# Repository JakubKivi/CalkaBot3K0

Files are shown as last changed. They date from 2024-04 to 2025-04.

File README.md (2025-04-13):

# CalkaBot3K0

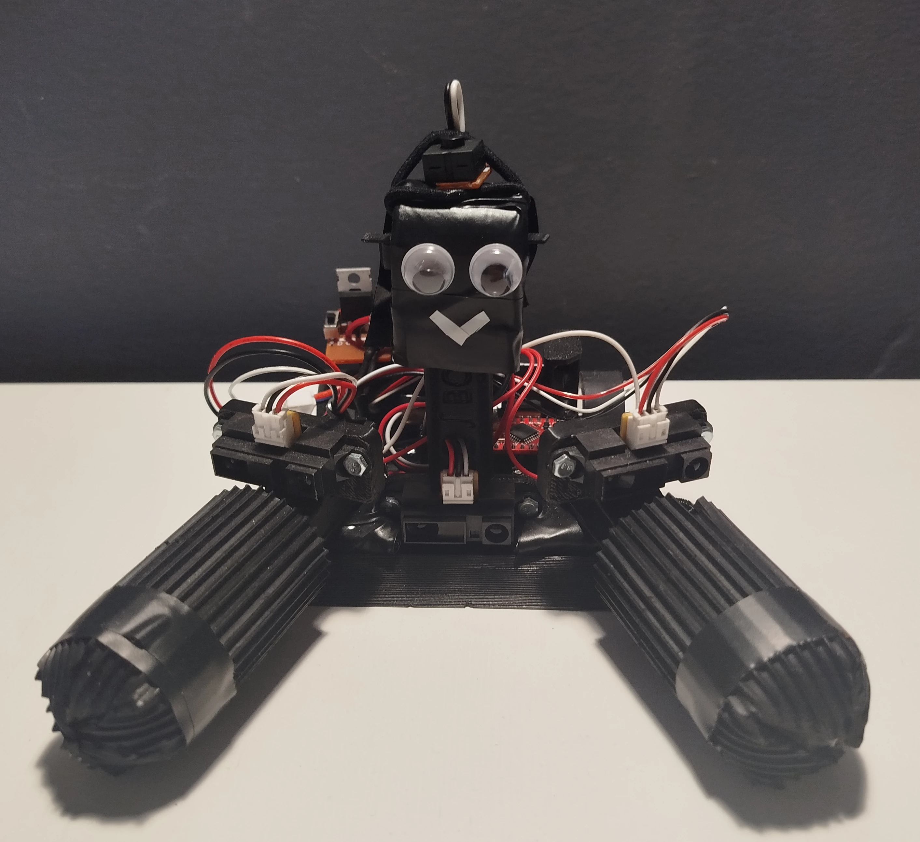
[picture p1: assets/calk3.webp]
CałkaBot3k0


Całkabot 3k0 is a mini-sumo robot equipped with arms designed to lift the opponent. Taking advantage of the lack of size restrictions after the round begins, this beauty you see in the picture unfolds its lifting arms. In the photo, it's already in the fully deployed position.

More info [here](https://jakubkivi.github.io#portfolio-modal-calk3)

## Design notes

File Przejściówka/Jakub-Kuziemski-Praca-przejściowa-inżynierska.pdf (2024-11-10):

# Praca przejściowa inżynierska

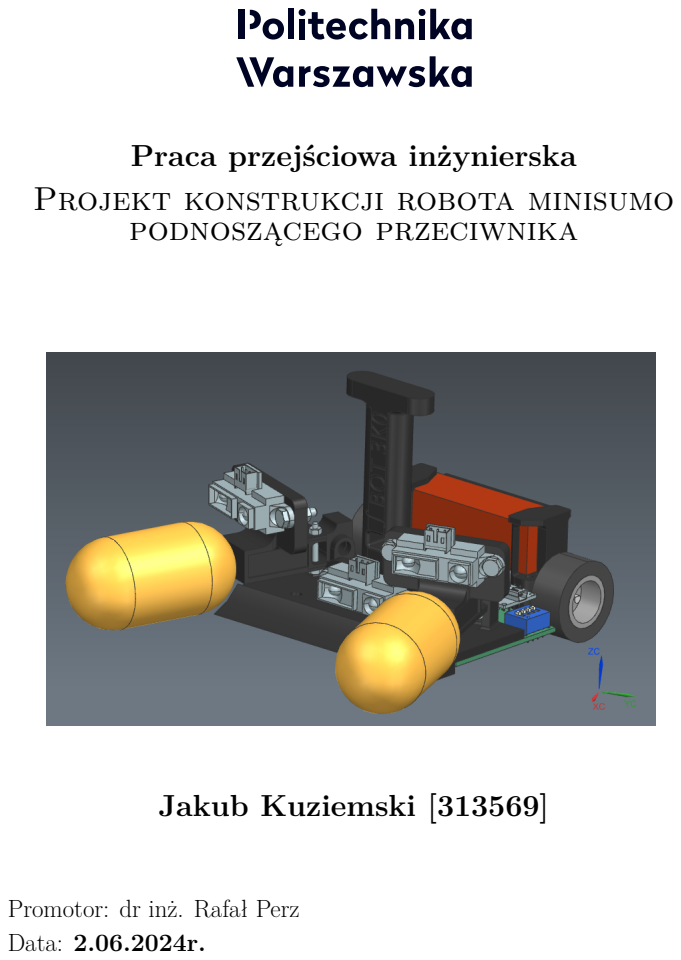
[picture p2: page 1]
podnoszącego przeciwnika; Jakub Kuziemski [313569]

Projekt konstrukcji robota minisumo

Promotor: dr inż. Rafał Perz
Data: 2.06.2024r.

Praca przejściowa inżynierska | Jakub Kuziemski [313569]

## Spis treści

1 Cel pracy | 3
2 Minisumo - wymagania | 3
3 Koncepcja robota minisumo wyposażonego w ramiona | 4
4 Pług robota | 5
5 Ramiona robota | 6
6 Mocowanie baterii | 7
7 Efekty | 8
8 Bibliografia | 10

Projekt konstrukcji robota minisumo podnoszącego przeciwnika Jakub Kuziemski [313569]

## 1 Cel pracy

Celem poniższej pracy jest zaprojektowanie konstrukcji robota klasy minisumo wyposażonego w rozkładane ramiona do podnoszenia przeciwników. Konstrukcja powinna spełniać wszystkie standardowe wymogi jakie musi spełniać robot minisumo, w tym określone wymiary i wagę. Ponadto, projekt powinien uwzględniać integrację wszystkich niezbędnych komponentów, takich jak czujniki, silniki, akumulatory oraz system sterowania, aby zapewnić pełną funkcjonalność robota w warunkach konkurencji minisumo. Niniejsza konstrukcja ma być możliwa do wydrukowania na drukarce 3D.

## 2 Minisumo - wymagania

Zawody walk robotów, na różnych płaszczyznach, są popularną formą zarówno edukacji w dziedzinie robotyki, jak i rozrywki samych konstruktorów. Zawody sumo jako jedne z nich, zyskały sobie znaczną popularność. Konkurencja ta polega na, autonomicznej rywalizacji robotów, nawiązując do tradycyjnych japońskich zapasów sumo. Celem rywalizacji jest wypchnięcie przeciwnika poza okrągłą arenę zwaną dohyo, przy zachowaniu pełnej autonomii działania. Walki sumo podzielone zostały na różne kategorie, w których ograniczają je wymiary i waga. Roboty klasy minisumo nie mogą przekroczyć, w momencie startu, rozmiarów 100x100mm, ani wagi 500g. Nie mają za to określonej maksymalnej wysokości, co zostanie wykorzystane w niniejszym projekcie. Konstrukcje są wyposażone w różnorodne czujniki, takie jak czujniki odległości, linii czy niekiedy nawet akcelerometry. Przy pomocy danych z owych czujników, za pomocą napisanego wcześniej programu robot musi namierzyć przeciwnika, a następnie, nie opuszczając samemu ringu, wypchnąć go. Wartymi nadmienienia ograniczeniami są także zakazy: intencjonalnego zakłócania odczytów przeciwnika, uszkadzania dohyo, strzelania, rzucania, intencjonalnego uszkadzania przeciwnika, a także przytwierdzania się do ziemi.

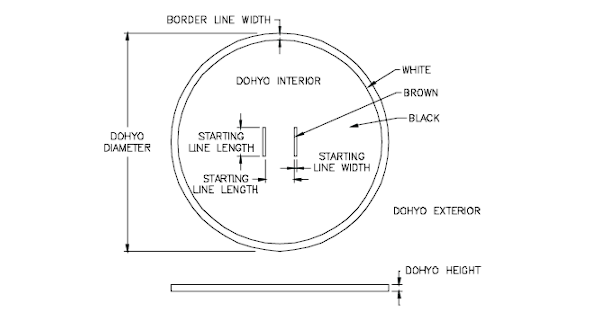
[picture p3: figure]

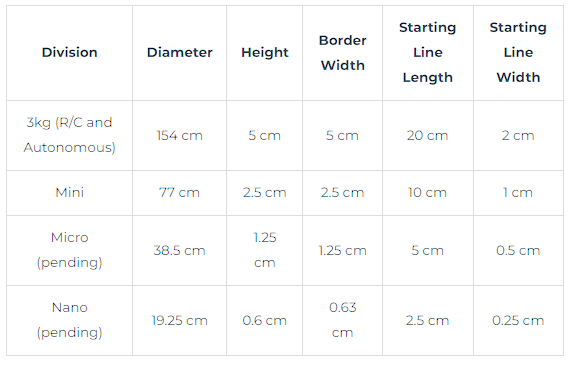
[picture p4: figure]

Ilustracja 1: Specyfikacja ringu w zależności od kategorii na zawodach "Robothon" w USA

## 3 Koncepcja robota minisumo wyposażonego w ramiona

Sformułowane wyżej wymagania, skumulowane z dość długą historią zawodów, stworzyły warunki do powstania preferowanych strategii i rozwiązań konstrukcyjnych. Roboty najczęściej mają masę dokładnie 500g, nisko osadzony środek ciężkości, kilka czujników zbliżeniowych do detekcji przeciwnika, dwa silniki z tyłu oraz niekiedy transoptory do wykrycia linii (nie jest to nawet konieczne przy niektórych strategiach).

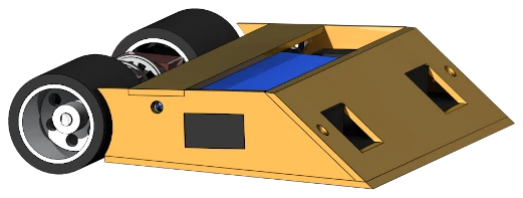
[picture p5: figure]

Ilustracja 2: Przykład najczęściej pojawiającego się robota minisumo

Brak ograniczenia co do wysokości robota daje jednak możliwości rozpatrywania nowych strategii. Niekiedy na zawodach pojawiają się roboty z rozkładanymi ramionami z białym materiałem, który ma zmylić przeciwnika.

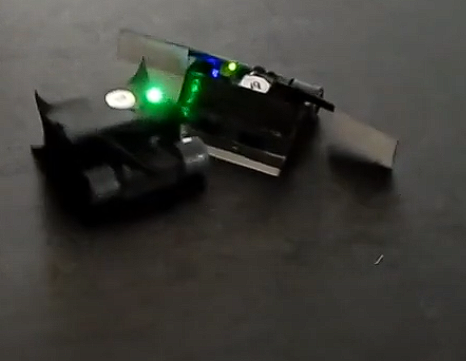
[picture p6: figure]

Ilustracja 3: Robot z rozkładanym mechanizmem dezorientacyjnym w zwarciu, na zawodach Robochallange w Meksyku

W związku z powyższym można postulować, zbudowanie robota z rozkładanymi ramionami, które będą nie tylko dezorientować przeciwnika, ale także, będą mogły go unieść. W korzystnym scenariuszu, w którym roboty spotkają się w zwarciu frontalnym, powodowałoby to zmniejszenie przyczepności oponenta, a w rezultacie wypchnięcie go poza Dohyo.

## 4 Pług robota

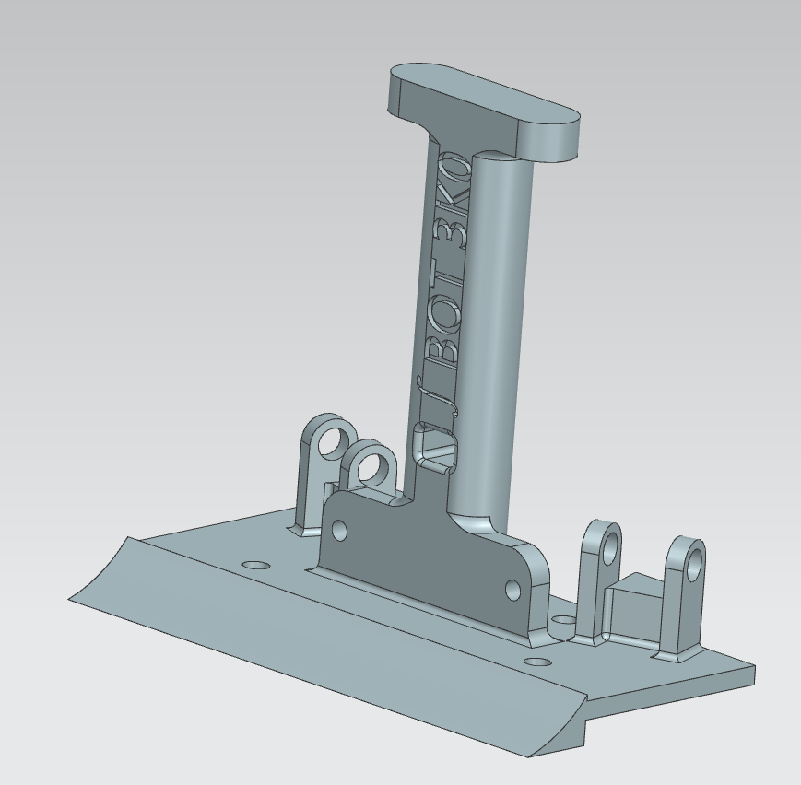
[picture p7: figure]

Ilustracja 4: Pług robota

Pracę rozpoczęto od budowy pługa. Jest to niewątpliwie jeden z kluczowych elementów każdego robota minisumo. Podniesienie przeciwnika jest często czynnikiem warunkującym zwycięstwo, dlatego konstruktorzy starają się aby pług był możliwie najniżej. Przy konstrukcji dwukołowej jest on najczęściej po prostu oparty o ziemie. Także w tym przypadku zdecydowano się na taką konstrukcje. Frontalna część w opisywanym robocie ma jednak inne ważne zadania, które zostały uwzględnione w jego budowie. Cztery otwory ϕ4mm służą do połączenia robota z płytką sterującą, która jednocześnie będzie częścią konstrukcji. Opcjonalnie w razie potrzeb można wykorzystać otwory do montażu ołowiu w celu dociążenia konstrukcji. W centralnej części pługa dostępne jest mocowanie do zamontowania czujnika Sharp GP2Y0A41SK0F. Jest to jeden z najpopularniejszych czujników zbliżeniowych stosowanych na zawodach minisumo. Cechuje go duża niezawodność i dokładność, niestety kosztem dość dużych rozmiarów. Ponadto tuż nad nim znajduje się słupek, który jest częścią prostego mechanizmu rozkładania się ramion robota. W środku słupka wykonano otwór na przewody w celu lepszej ich organizacji. Symetrycznie po obu stronach pługa będą montowane ramiona robota, przy pomocy sworzni. Jednocześnie konstrukcja ta wraz z konstrukcją ramienia tworzą ogranicznik, tak aby ramie nie mogło rozłożyć się do tyłu.

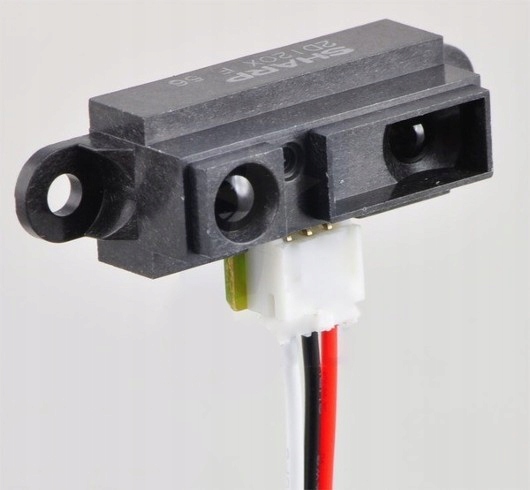
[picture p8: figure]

Ilustracja 5: Czujnik Sharp GP2Y0A41SK0F

## 5 Ramiona robota

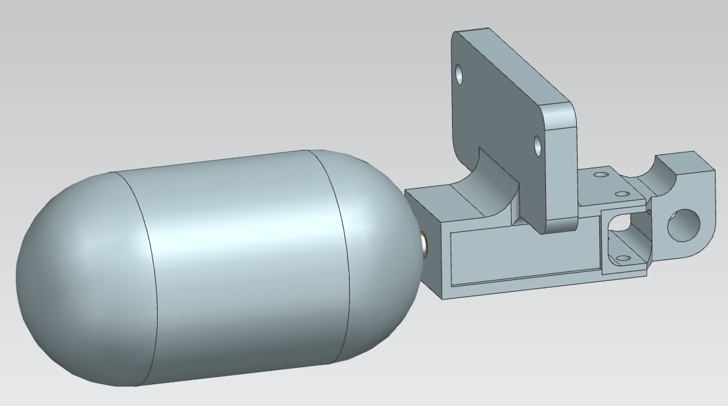
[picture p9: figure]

Ilustracja 6: Projekt ręki robota

Kluczowym elementem opisywanej konstrukcji są oczywiście ramiona. Ramię robota składa się z dwóch skręcanych ze sobą elementów. Pomiędzy nimi ma znajdować się silnik Pololu 998, który jest jednym z najpopularniej stosowanych silników w robotach minisumo, z racji na swoją dużą moc w sosunku do rozmiarów. Ramię jest tak skonstruowane, że silnik pomiędzy dwoma jego częściami jest nie tylko unieruchomiony, ale także odizolowany od kurzu czy włosów, co istotne dla niezawodności działania przekładni. W górnej częsci ramienia skonstruowano mocowanie dla kolejnego czujnika GP2Y0A41SK0F. Poza otworami na śruby łączące obie części ramienia, stworzono też oczywiście otwór na wał silnika. Część mocowana do wału jest zamodelowana poglądowo i jako, że nie będzie drukowana, pozostaje poza obszarem niniejszej pracy. Tylna część konstrukcji ramienia ma też otwór na przewody do silnika, a także otwór do współpracy z pługiem o czym była mowa w rozdziale 4.

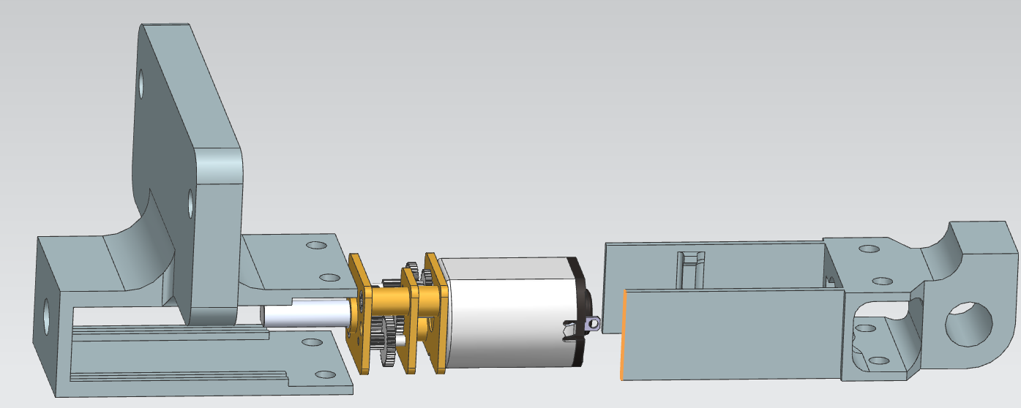
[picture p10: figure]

Ilustracja 7: Rozłożona ręka robota

## 6 Mocowanie baterii

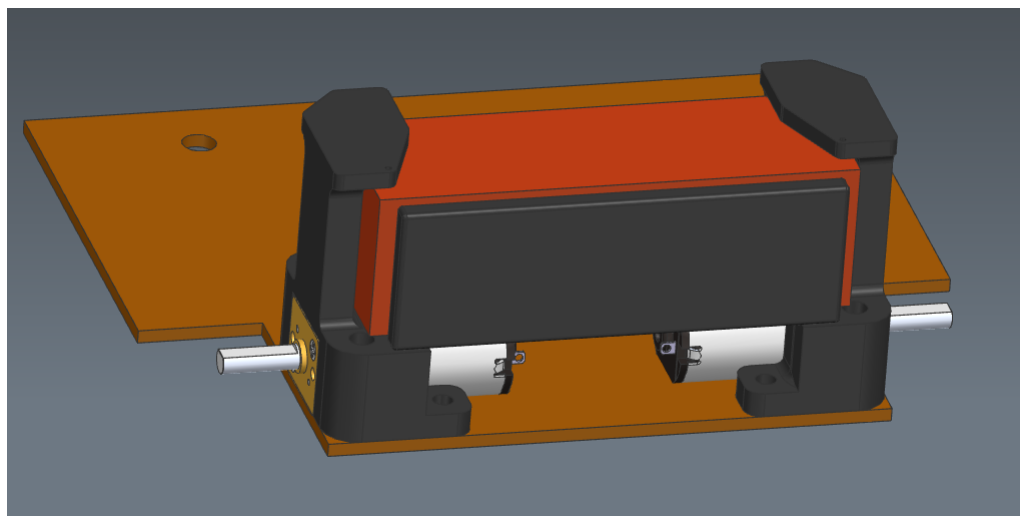
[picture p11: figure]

Ilustracja 8: Mocowanie baterii i silników wraz z modelem baterii (czerwony) i płytki (pomarańczowy)

Tylna część konstrukcji robota jest odpowiedzialna za trzymanie baterii, oraz mocowanie silników do płytki PCB. Można podzielić ją na 3 części. Dwa odbite symetrycznie elementy przytwierdzone do płytki przy pomocy 3 śrub M3 utrzymują silniki w bezruchu, ale także (ponownie) izolują przekładnie od ewentualnych zabrudzeń. Pozostała część tych elementów jest zaprojektowana by odebrać możliwość ruchu baterii we wszystkich kierunkach poza tyłem robota. Tam zaprojektowano trzeci element który można wyjąć na czas zmiany akumulatora, lub włożyć tak aby kompletnie uniemożliwić jego ruch.

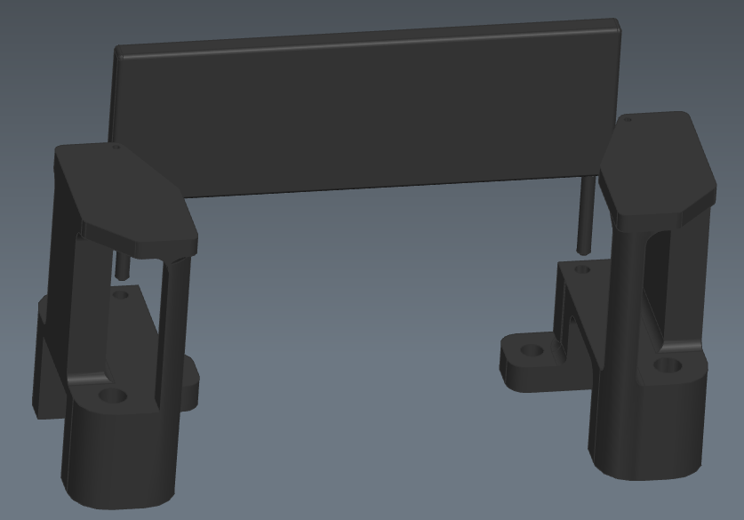
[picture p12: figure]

Ilustracja 9: Rozłożone mocowanie baterii

## 7 Efekty

Łącząc wszystkie wyżej wymienione elementy, oraz dodając kilka gotowych lub poglądowych, otrzymujemy projekt robota minisumo wyposażonego w ramiona, zdolne do podnoszenia przeciwników. Robot rozpoczyna walkę w konfiguracji widocznej na ilustracji 10. Następnie następuje start silników w ramionach i robot odpycha się od słupka zamontowanego na pługu i przechodzi do konfiguracji widocznej na ilustracji 11. Przy pomocy zestawu czujników, robot ma lokalizować przeciwnika, a następnie gdy ten znajdzie się pomiędzy jego ramionami unieść go kręcącymi się nadal silnikami.

Widoczna konstrukcja pokazuje, że w kategorii robotów minisumo, można zaprojektować robota zdolnego do rozkładania własnych ramion, a następnie podniesienia nimi przeciwnika. Niniejsza praca stanowi dobrą podstawę do zbudowania takiego robota i przeprowadzenia testów praktycznych takiego rozwiązania.

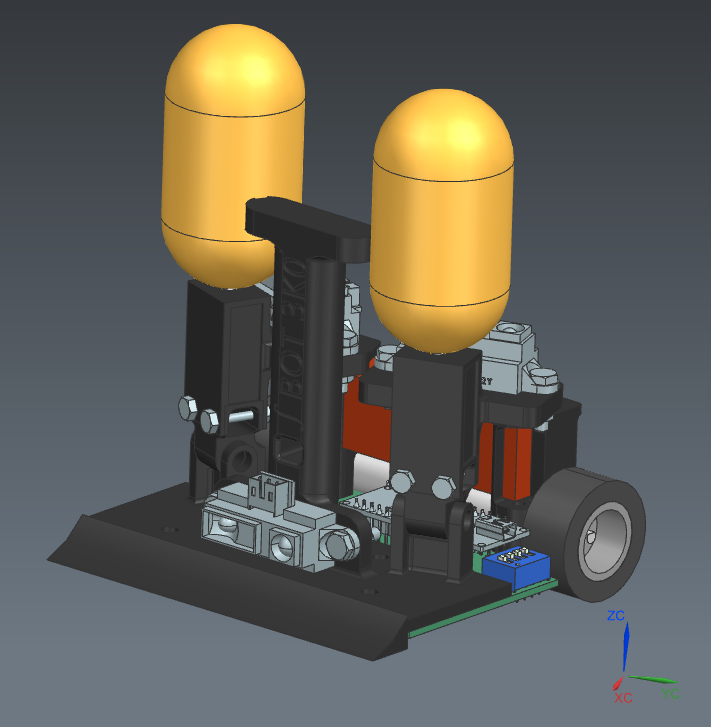
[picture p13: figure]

Ilustracja 10: Kompletna konstrukcja robota

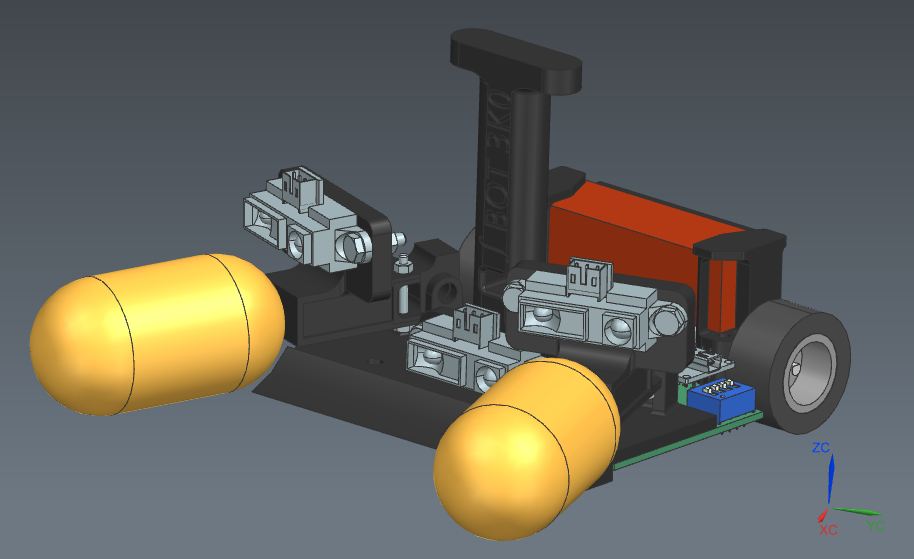
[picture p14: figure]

Ilustracja 11: Kompletna konstrukcja robota z rozłożonymi ramionami

## 8 Bibliografia

1. https://robothon.org/rules-sumo/
2. https://mdrwiega.com/robot-minisumo-banshee/
3. Ja mam Robot!, "Komputer Świat Ekspert" 2007

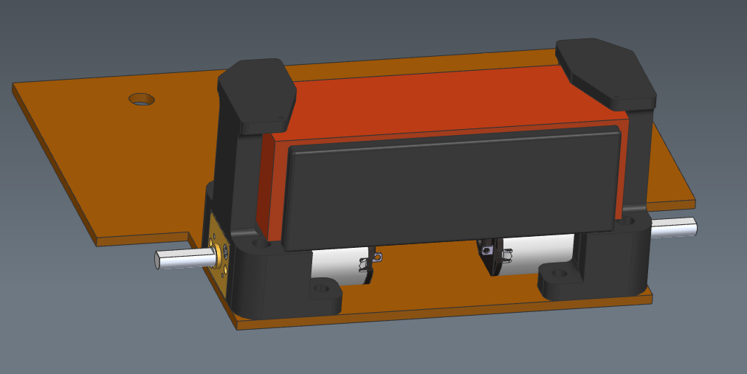
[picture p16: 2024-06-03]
Przejściówka/mocowaniebaterii.PNG

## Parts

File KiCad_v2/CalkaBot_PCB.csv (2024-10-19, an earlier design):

Reference | Value | Datasheet | Footprint | Qty | DNP
A1 | Arduino_Nano_v2.x | https://www.arduino.cc/en/uploads/Main/ArduinoNanoManual23.pdf | Module:Arduino_Nano | 1
C1 | 0u33 | ~ | Capacitor_SMD:C_0805_2012Metric_Pad1.18x1.45mm_HandSolder | 1
C2,C7,C9,C11,C12 | 0u1 | ~ | Capacitor_SMD:C_0805_2012Metric_Pad1.18x1.45mm_HandSolder | 5
C3 | 10n | ~ | Capacitor_SMD:C_0805_2012Metric_Pad1.18x1.45mm_HandSolder | 1
C4 | 200n | ~ | Capacitor_SMD:C_0805_2012Metric_Pad1.18x1.45mm_HandSolder | 1
C5,C6 | 5n6 | ~ | Capacitor_SMD:C_0805_2012Metric_Pad1.18x1.45mm_HandSolder | 2
C8 | 100u | ~ | Capacitor_SMD:CP_Elec_8x10.5 | 1
CR1 | L6225PD | L6225PD | Package_SO:SO-20-1EP_7.52x12.825mm_P1.27mm_EP6.045x12.09mm_Mask3.56x4.47mm_ThermalVias | 1
D1,D2 | 1N4148WT | https://www.diodes.com/assets/Datasheets/ds30396.pdf | Diode_SMD:D_SOD-523 | 2
D3 | SS14 | ~ | Diode_SMD:D_SMA_Handsoldering | 1
J1,J2,J3 | Conn_01x03_Pin | ~ | Connector_JST:JST_PH_B3B-PH-K_1x03_P2.00mm_Vertical | 3
J4 | Conn_01x02_Pin | ~ | Connector_PinHeader_2.54mm:PinHeader_1x02_P2.54mm_Vertical | 1
J5 | MOTOR3 | ~ | Connector_PinHeader_2.54mm:PinHeader_1x02_P2.54mm_Vertical | 1
J6 | StartModule | ~ | Connector_PinHeader_2.54mm:PinHeader_1x03_P2.54mm_Vertical | 1
M1 | Motor_Right | ~ | CalkaBot3k0:CalkBot3k0_Motor_Right | 1
M2 | Motor_Left | ~ | CalkaBot3k0:CalkBot3k0_Motor_Left | 1
Q1,Q2 | KTIR0711S | KTIR0711S | footprints:KTIR0711S_KNB | 2
Q3 | IRLL014NTRPBF | http://www.b-kainka.de/Daten/Transistor/BC108.pdf | Package_TO_SOT_SMD:SOT-223 | 1
R1,R3 | 20k | ~ | Resistor_SMD:R_0805_2012Metric_Pad1.20x1.40mm_HandSolder | 2
R2 | 100R | ~ | Resistor_SMD:R_0805_2012Metric_Pad1.20x1.40mm_HandSolder | 1
R4,R5 | 220 | ~ | Resistor_SMD:R_0805_2012Metric_Pad1.20x1.40mm_HandSolder | 2
R6,R7 | 100k | ~ | Resistor_SMD:R_0805_2012Metric_Pad1.20x1.40mm_HandSolder | 2
SW1 | SW_DIP_x04 | ~ | Button_Switch_THT:SW_DIP_SPSTx04_Slide_9.78x12.34mm_W7.62mm_P2.54mm | 1
U1 | L78M05CDT-TR |  | L78M05CDT-TR:VREG_L78M05CDT-TR | 1

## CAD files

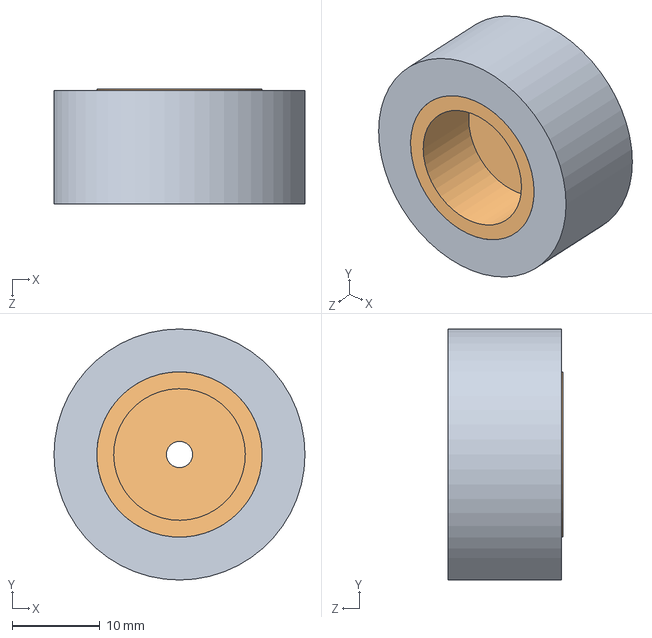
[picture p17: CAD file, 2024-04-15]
NX/wheel-solarbotics-rw2i-internally-mounted-1.snapshot.4/koło_solarbotics.SLDASM
28.6 x 28.6 x 13.1 mm
opona solarbotics
felga_solarbotics

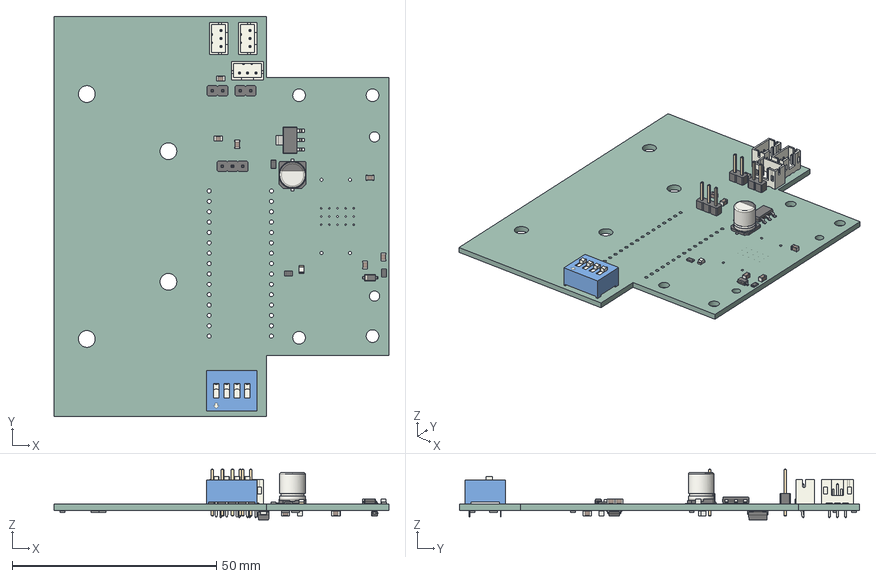
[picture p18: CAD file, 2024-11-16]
NX/CalkaBot_PCB.step
82.0 x 98.0 x 12.5 mm
LED_0805_2012Metric
CP_Elec_63x77
SOT_223
C_0805_2012Metric x 10
SW_DIP_SPSTx04_Slide_978x1234mm_W762mm_P254mm
R_0805_2012Metric x 9
PinHeader_1x02_P254mm_Vertical x 2
PinHeader_1x03_P254mm_Vertical
JST_B3B_PH_K x 3
D_SOD_123 x 2
D_SMA
CalkaBot_PCB_PCB

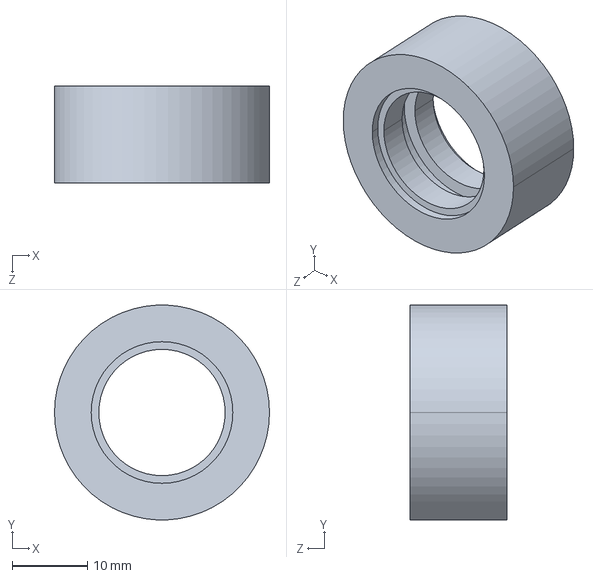
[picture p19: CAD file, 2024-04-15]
NX/wheel-solarbotics-rw2i-internally-mounted-1.snapshot.4/STEP/opona solarbotics.STEP
28.6 x 28.6 x 13.0 mm

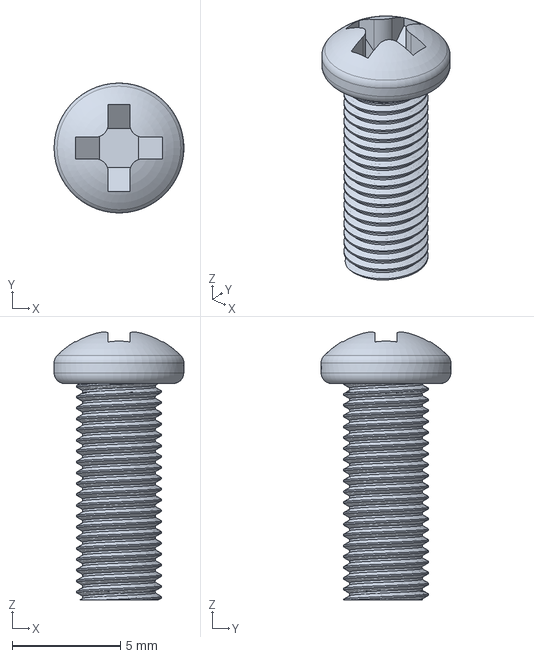
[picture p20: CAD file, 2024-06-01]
NX/M4 x 10mm.step
6.00 x 6.00 x 12.4 mm

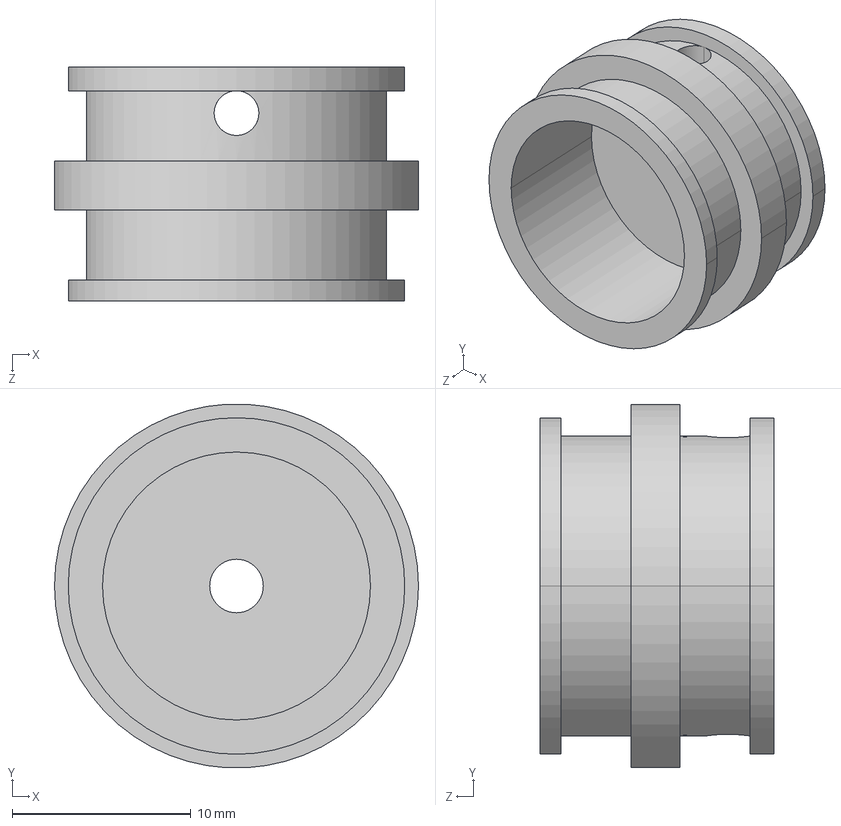
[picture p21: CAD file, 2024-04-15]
NX/wheel-solarbotics-rw2i-internally-mounted-1.snapshot.4/STEP/felga_solarbotics.STEP
20.4 x 20.4 x 13.1 mm

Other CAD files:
NX/Akumulator.prt
NX/ArduinoNano.prt
NX/CP_Elec_8x10.5.prt
NX/CP_Elec_8x105.prt
NX/C_0805_2012Metric.prt
NX/C_0805_2012Metric1576.prt
NX/CalkaBot_PCB.prt
NX/CalkaBot_PCB_step.prt
NX/D_SMA.prt
NX/D_SMA17935.prt
NX/D_SOD-523.prt
NX/D_SOD_523.prt
NX/GP2Y0A21YK0F.prt
NX/JST_B3B_PH_K.prt
NX/JST_B3B_PH_K11783.prt
NX/JST_PH_B3B-PH-K_1x03_P2.00mm_Vertical.prt
NX/JST_PH_B3B-PH-K_1x03_P2.00mm_Vertical11760.prt
NX/M2_Nakretka.prt
NX/M2_Sruba.prt
NX/M3_Nakretka.prt
NX/M3_Sruba.prt
NX/M4 x 10mm_step.prt
NX/Obudowa_Reki.prt
NX/Obudowa_Reki_Tyl.prt
NX/PinHeader_1x02_P2.54mm_Vertical.prt
NX/PinHeader_1x02_P254mm_Vertical.prt
NX/PinHeader_1x03_P2.54mm_Vertical.prt
NX/PinHeader_1x03_P254mm_Vertical.prt
NX/Podstawa.prt
NX/R_0805_2012Metric.prt
NX/R_0805_2012Metric10951.prt
NX/Reka_Zlozenie.prt
NX/SOT-223.prt
NX/SOT_223.prt
NX/SW_DIP_SPSTx04_Slide_9.78x12.34mm_W7.62mm_P2.54mm.prt
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

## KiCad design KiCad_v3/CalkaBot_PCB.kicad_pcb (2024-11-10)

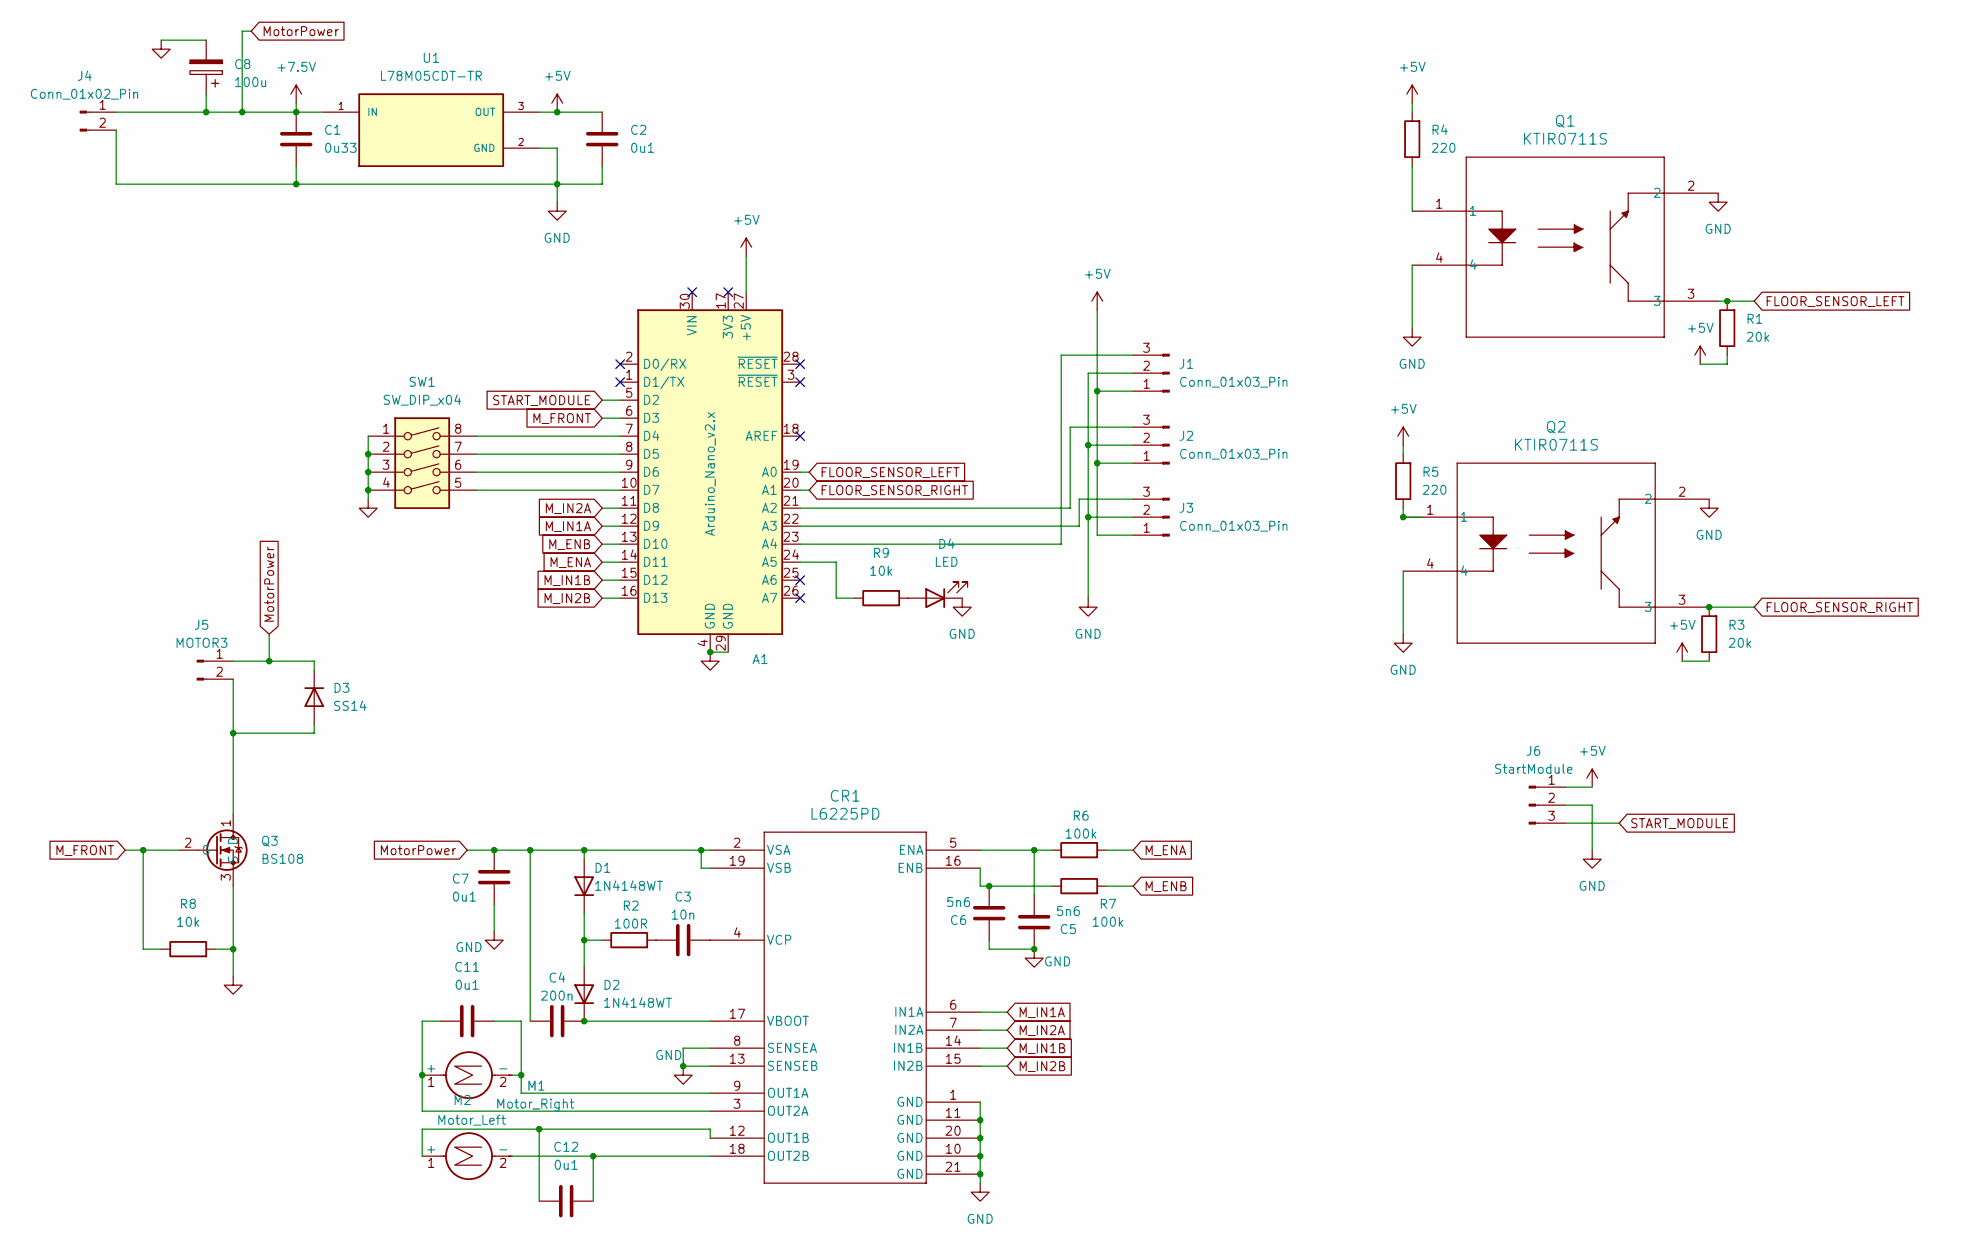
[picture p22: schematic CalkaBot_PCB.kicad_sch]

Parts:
A1: Arduino_Nano_v2.x; Arduino_Nano
C1: 0u33; C_0805_2012Metric_Pad1.18x1.45mm_HandSolder
C2, C7, C11, C12: 0u1; C_0805_2012Metric_Pad1.18x1.45mm_HandSolder
C3: 10n; C_0805_2012Metric_Pad1.18x1.45mm_HandSolder
C4: 200n; C_0805_2012Metric_Pad1.18x1.45mm_HandSolder
C5, C6: 5n6; C_0805_2012Metric_Pad1.18x1.45mm_HandSolder
C8: 100u; CP_Elec_6.3x7.7
CR1: L6225PD
D1, D2: 1N4148WT; D_SOD-123
D3: SS14; D_SMA_Handsoldering
D4: LED; LED_0805_2012Metric_Pad1.15x1.40mm_HandSolder
J1, J2, J3: Conn_01x03_Pin; JST_PH_B3B-PH-K_1x03_P2.00mm_Vertical
J4: Conn_01x02_Pin; PinHeader_1x02_P2.54mm_Vertical
J5: MOTOR3; PinHeader_1x02_P2.54mm_Vertical
J6: StartModule; PinHeader_1x03_P2.54mm_Vertical
M1: Motor_Right; CalkBot3k0_Motor_Right
M2: Motor_Left; CalkBot3k0_Motor_Left
Q1, Q2: KTIR0711S
Q3: BS108; SOT-223-IRLL014NTRPBF
R1, R3: 20k; R_0805_2012Metric_Pad1.20x1.40mm_HandSolder
R2: 100R; R_0805_2012Metric_Pad1.20x1.40mm_HandSolder
R4, R5: 220; R_0805_2012Metric_Pad1.20x1.40mm_HandSolder
R6, R7: 100k; R_0805_2012Metric_Pad1.20x1.40mm_HandSolder
R8, R9: 10k; R_0805_2012Metric_Pad1.20x1.40mm_HandSolder
SW1: SW_DIP_x04; SW_DIP_SPSTx04_Slide_9.78x12.34mm_W7.62mm_P2.54mm
U1: L78M05CDT-TR; VREG_L78M05CDT-TR; PARTREV 24

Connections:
+5V: A1.27 (+5V), C2.1, J1.1, J2.1, J3.1, J6.1, R1.1, R3.1, R4.2, R5.2, U1.3 (OUT)
FLOOR_SENSOR_LEFT: A1.19 (A0), Q1.3, R1.2
FLOOR_SENSOR_RIGHT: A1.20 (A1), Q2.3, R3.2
GND: A1.4 (GND), A1.29 (GND), C1.2, C2.2, C5.1, C6.1, C7.2, C8.2, CR1.1 (GND), CR1.8 (SENSEA), CR1.10 (GND), CR1.11 (GND), CR1.13 (SENSEB), CR1.20 (GND), CR1.21 (GND), D4.1 (K), J1.2, J2.2, J3.2, J4.2, J6.2, Q1.2, Q1.4, Q2.2, Q2.4, Q3.3 (S), R8.2, SW1.1, SW1.2, SW1.3, SW1.4, U1.2 (GND); also elsewhere on the board
M_ENA: A1.14 (D11), R6.2
M_ENB: A1.13 (D10), R7.2
M_FRONT: A1.6 (D3), Q3.2 (G), R8.1
M_IN1A: A1.12 (D9), CR1.6 (IN1A)
M_IN1B: A1.15 (D12), CR1.14 (IN1B)
M_IN2A: A1.11 (D8), CR1.7 (IN2A)
M_IN2B: A1.16 (D13), CR1.15 (IN2B)
MotorPower: C1.1, C4.1, C7.1, C8.1, CR1.2 (VSA), CR1.19 (VSB), D1.2 (A), D3.1 (K), J4.1, J5.1, U1.1 (IN); also elsewhere on the board
unnamed: A1.21 (A2), J2.3
unnamed: A1.22 (A3), J3.3
unnamed: A1.23 (A4), J1.3
unnamed: A1.24 (A5), R9.1
unnamed: A1.7 (D4), SW1.8
unnamed: A1.8 (D5), SW1.7
unnamed: A1.9 (D6), SW1.6
unnamed: A1.10 (D7), SW1.5
unnamed: C3.1, R2.2
unnamed: C5.2, CR1.5 (ENA), R6.1
unnamed: C6.2, CR1.16 (ENB), R7.1
unnamed: C11.1, CR1.9 (OUT1A), M1.2 (-)
unnamed: C12.2, CR1.12 (OUT1B), M2.1 (+)
unnamed: C11.2, CR1.3 (OUT2A), M1.1 (+)
unnamed: C12.1, CR1.18 (OUT2B), M2.2 (-)
unnamed: C4.2, CR1.17 (VBOOT), D2.1 (K)
unnamed: C3.2, CR1.4 (VCP)
unnamed: D1.1 (K), D2.2 (A), R2.1
unnamed: D3.2 (A), J5.2, Q3.1 (D)
unnamed: D4.2 (A), R9.2
unnamed: Q1.1, R4.1
unnamed: Q2.1, R5.1
START_MODULE: A1.5 (D2), J6.3

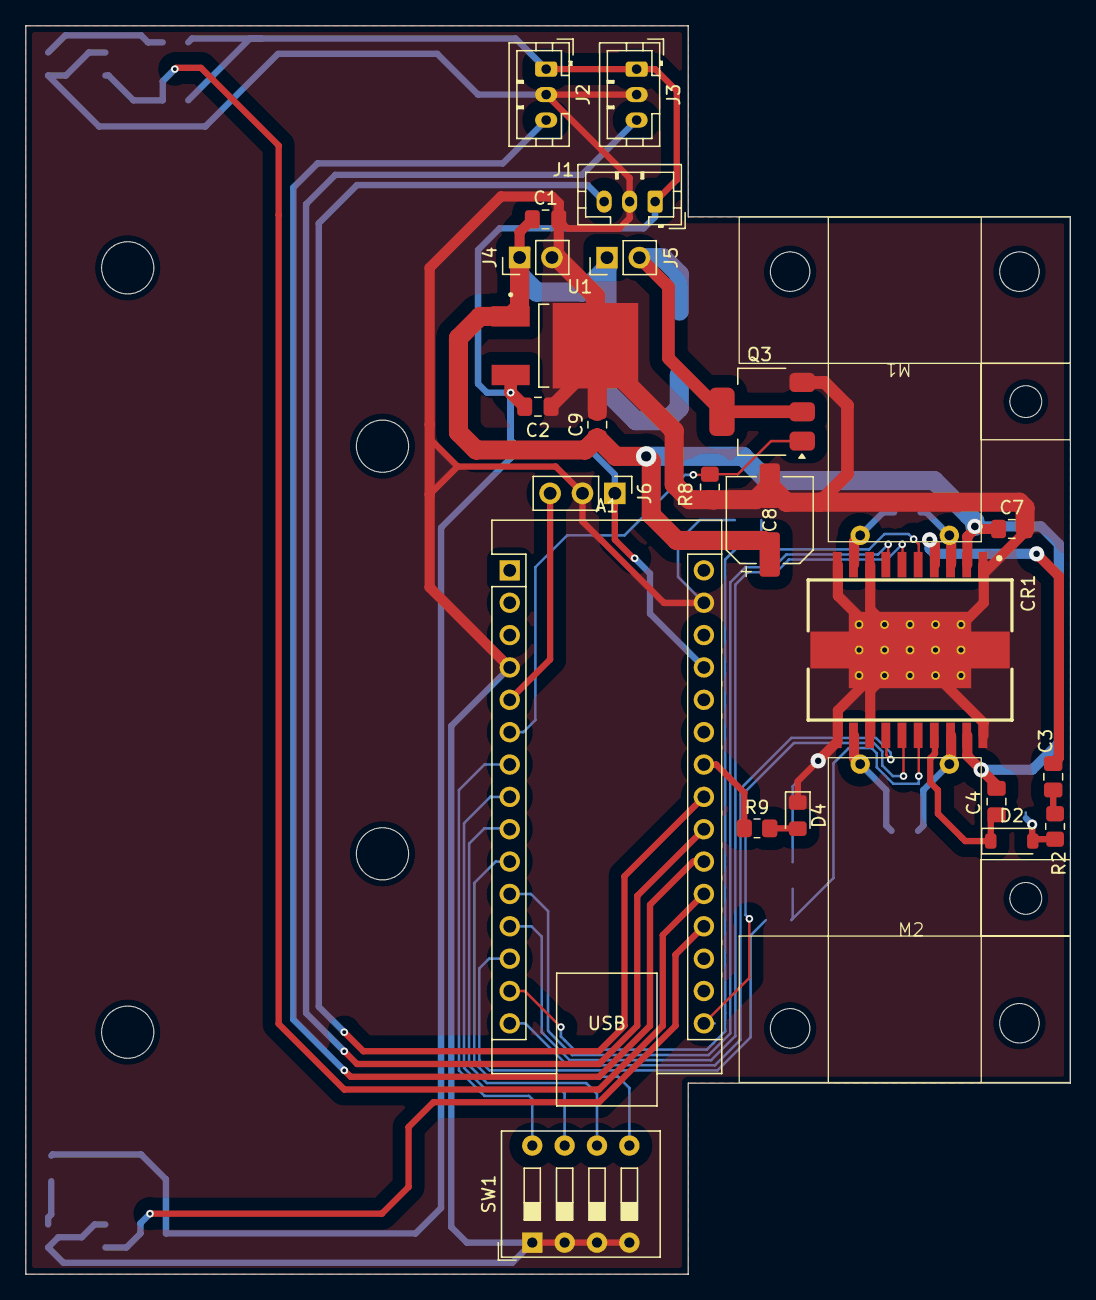
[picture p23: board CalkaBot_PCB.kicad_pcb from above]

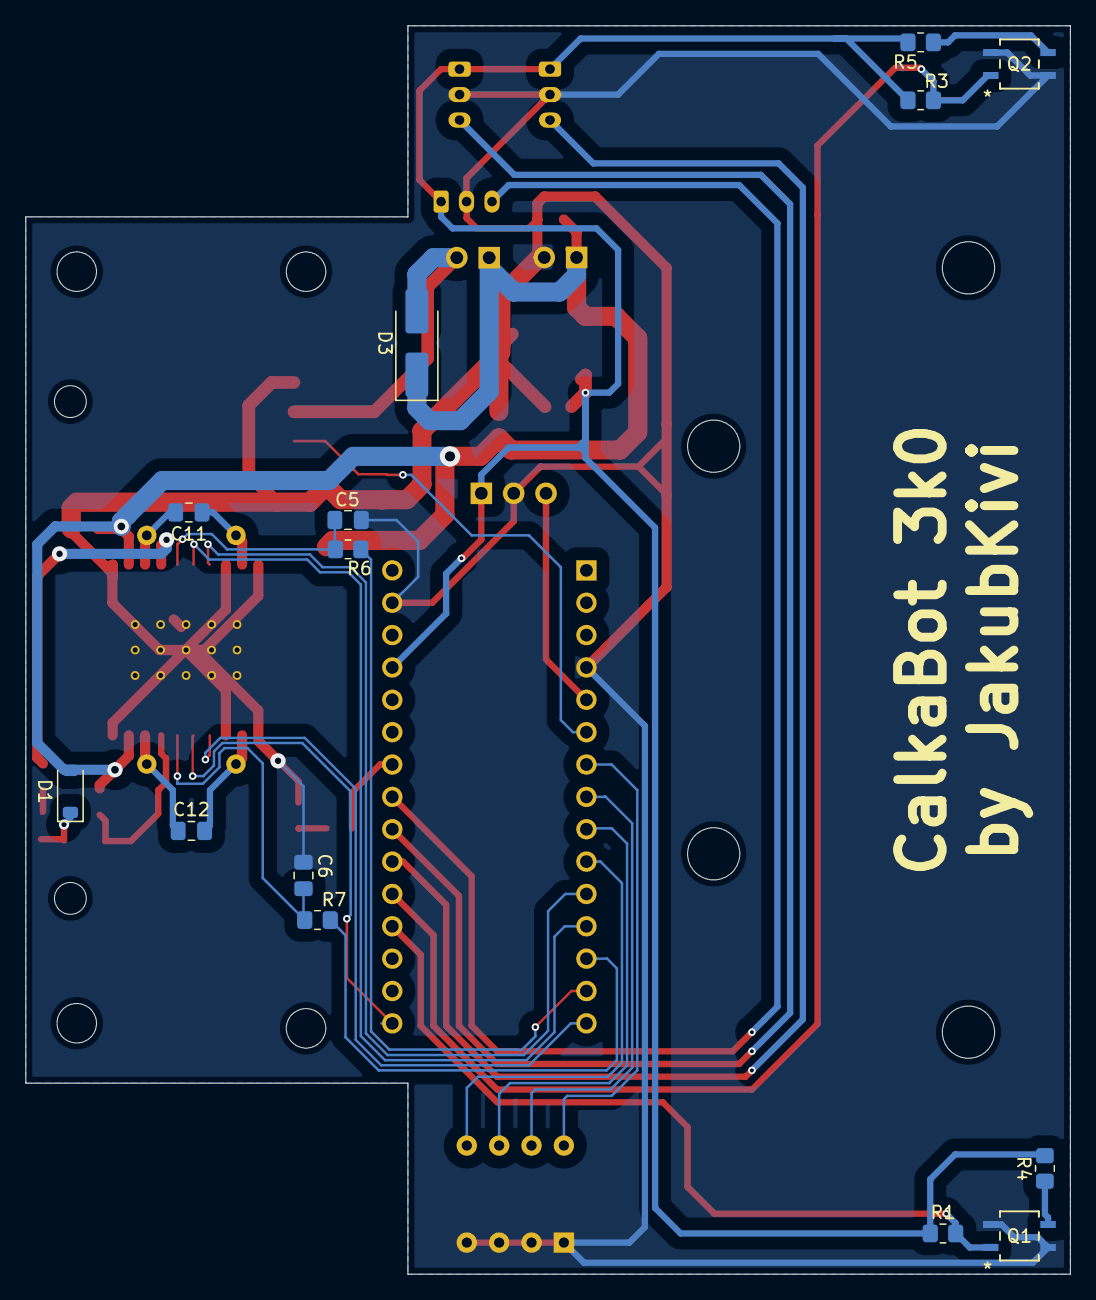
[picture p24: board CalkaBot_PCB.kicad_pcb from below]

Board: 2 copper layers, 82.0 x 98.0 mm, 39 parts (14 on the bottom side), 35 nets.

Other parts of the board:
C9: 0u1; C_0805_2012Metric_Pad1.18x1.45mm_HandSolder

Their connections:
GND: C9.2; also elsewhere on the board
MotorPower: C9.1; also elsewhere on the board

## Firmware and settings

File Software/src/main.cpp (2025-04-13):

#include "../include/config.h"
#include "../include/FrontMotor.h"  
#include "../include/InputManager.h"
#include "../include/BuildLED.h"
#include "../include/Sensor.h"
#include "../include/Robot.h"
#include "../lib/SoftPWM.h"



SOFTPWM_DEFINE_CHANNEL(0, ROBOT_RIGHT_DDR, ROBOT_RIGHT_PORT, ROBOT_RIGHT_PIN);   // Soft PWM na Pin 13
SOFTPWM_DEFINE_CHANNEL(1, ROBOT_LEFT_DDR, ROBOT_LEFT_PORT, ROBOT_LEFT_PIN);      // Soft PWM na Pin 12
SOFTPWM_DEFINE_OBJECT_WITH_PWM_LEVELS(2, 255);                                   // Makra dla SoftPWM

Robot calkaBot(&DDRB, &PORTB, PB3, PB0, PB2, PB1);                      // Silniki w kołach
InputManager inputManager(&PORTD, &DDRD, &PIND, PD4, PD5, PD6, PD7);    // Switche na płytce
FrontMotor frontMotor(&PORTD, &DDRD, PD3);                              // Sterowanie ramionami
BuildLed buildLed(&PORTC, &DDRC, PC5);                                  // Wbudowana dioda informacyjna

Sensor floorLeft(0);                                                    // Czujniki linii, lewy
Sensor floorRight(1);                                                   //               , prawy

Sensor front(3);                                                        // Czujniki przeciwnika , środkowy
Sensor left(4);                                                         //                      , lewy
Sensor right(2);                                                        //                      , prawy


void setup() {
    Palatis::SoftPWM.begin(200);  
    Palatis::SoftPWM.set(0, FULL_SPEED); 
    Palatis::SoftPWM.set(1, FULL_SPEED);    //dla pozycjonowania na starcie

    pinMode(2, INPUT_PULLUP);
    Serial.begin(9600);

}

bool positioned = false;

bool curve = true;

void loop() {
    if (digitalRead(2) or inputManager.readDecimalValue() ==0){  
        switch (inputManager.readDecimalValue())
        {
            case 0:
                positioned = false;
                calkaBot.stop();
                frontMotor.off();
                Serial.println("Left: "+ String(left.read()) + "    Mid: " + String(front.read()) +"       Right: " + String(right.read() ));
                
                if (front.read() > FRONT_THRESHOLD or right.read() > FRONT_RIGHT_THRESHOLD or left.read() > FRONT_LEFT_THRESHOLD)
                {
                    buildLed.on();
                }else{
                    buildLed.off();
                }
                _delay_ms(500);
            break;
            


            case 1:
            case 2:                    
            case 3:         //lewo bez szukania
            case 5:
            case 6:
            case 7:         //prawo bez szukania
            case 9:
            case 10:
            case 11:        //lewo z szukaniem
            case 13:
            case 14:
            case 15:        //prawo z szukaniem
                if (!positioned)
                {
                    delay(3000);
                    int positioningTime = 1;
                    if(inputManager.readPin(PD4)) positioningTime+=1;
                    if(inputManager.readPin(PD5)) positioningTime+=2;
                    calkaBot.position(&left, &front, &right, positioningTime, inputManager.readPin(PD6));
                    positioned = true; 
                    frontMotor.on();

                }else{

                    if(front.read() > FRONT_FULLSPEED_THRESHOLD){           //NA BLISKO RURA!
                        Palatis::SoftPWM.set(0, FULL_SPEED); 
                        Palatis::SoftPWM.set(1, FULL_SPEED); 
                    }else{
                        Palatis::SoftPWM.set(0, SEARCH_SPEED); 
                        Palatis::SoftPWM.set(1, SEARCH_SPEED); 
                    }

                    if (front.read()>FRONT_THRESHOLD){
                        calkaBot.forward();

                    }else if(right.read() > FRONT_RIGHT_THRESHOLD){
                        calkaBot.rightCurve();

                    }else if(left.read() > FRONT_LEFT_THRESHOLD){
                        calkaBot.leftCurve();

                    }else{
                        if (inputManager.readPin(PD7))        //Kręcenie włączone
                        {
                            if (floorLeft.read() < LEFT_FLOOR_THRESHOLD)
                            {
                                calkaBot.backward();
                                _delay_ms(LINE_DETCTION_BACKWARD_LENGHT);
                                calkaBot.rightTurn();
                                _delay_ms(LINE_DETCTION_RIGHT_TURN_LENGHT);

                            }else if(floorRight.read() < RIGHT_FLOOR_THRESHOLD){
                                calkaBot.backward();
                                _delay_ms(LINE_DETCTION_BACKWARD_LENGHT);
                                calkaBot.rightTurn();
                                _delay_ms(LINE_DETCTION_LEFT_TURN_LENGHT);

                            }else{
                                int i=0;
                                if (curve){
                                    calkaBot.leftTurn();
                                    while (i < SEARCH_LEFT_CURVE){
                                        delay(10);
                                        i+=10;
                                        if (right.read() > FRONT_RIGHT_THRESHOLD || front.read()>FRONT_THRESHOLD || left.read() > FRONT_LEFT_THRESHOLD)
                                            break;
                                        
                                    } 

                                }else{
                                    calkaBot.rightTurn();
                                    while (i < SEARCH_RIGHT_CURVE){
                                        delay(10);
                                        i+=10;
                                        if (right.read() > FRONT_RIGHT_THRESHOLD || front.read()>FRONT_THRESHOLD || left.read() > FRONT_LEFT_THRESHOLD)
                                            break;
                                        
                                    } 
                                }
                                curve = !curve;
                            }
                        }else{
                            calkaBot.stop();
                        }
                    }
                    frontMotor.on();
                    delay(10);
                }
            break;

            case 4:
            case 8:
            case 12:            
                frontMotor.off();
                calkaBot.forward();
                buildLed.toggle();
                _delay_ms(100);
            break;
            
            default:
                positioned = false;
                frontMotor.off();
                calkaBot.stop();
                buildLed.toggle();
                _delay_ms(100);
            break;
        }
    }else{
        positioned = false;
        frontMotor.off();
        calkaBot.stop();
        buildLed.toggle();
        _delay_ms(100);
    }
}

    // ===================================== INŻYNIERKA ====================(tak. z błędami. późno było xd ale padaka xd)======== //
    // while (!positioned)
    // {
    //     if (digitalRead(2))   // Sygnał startowy na złączu J6
    //     {
    //         frontMotor.on();    //Uruchom silniki w ramionach
    //         if (inputManager.readPin(4)) 
    //         {
    //             //Wykonaj program specjalny

    //         }else{
    //             if (inputManager.readPin(1))        //Przodem do siebie
    //             {
    //                 if (inputManager.readPin(2))            //korekta w lewo
    //                 {
    //                     calkaBot.leftTurn();
    //                     delay(ALIGNMENT_TURN_LENGHT);
    //                     positioned=true;
    //                 }else{                                 //korekta w prawo
    //                     calkaBot.rightTurn();
    //                     delay(ALIGNMENT_TURN_LENGHT);
    //                 }
                    
    //             }else{                              //Tyłem do siebie
    //                 if (inputManager.readPin(2))            //korekta w lewo
    //                 {
    //                     calkaBot.leftTurn();
    //                     delay(BACKWARDS_ALIGNMENT_TURN_LENGHT);
    //                 }else{                                 //korekta w prawo
    //                     calkaBot.rightTurn();
    //                     delay(BACKWARDS_ALIGNMENT_TURN_LENGHT);
    //                 }
    //             }
                
    //         }
    //         positioned=true;
    //     }
    // }

    // while(positioned){
    //     if (front.read()>FRONT_THRESHOLD)
    //     {
    //         calkaBot.forward();
    //     }else if(right.read()>FRONT_THRESHOLD){
    //         calkaBot.rightCurve();
    //     }else if(left.read()>FRONT_THRESHOLD){
    //         calkaBot.leftCurve();
    //     }else{
    //         if (inputManager.readPin(3))        //Przeszukiwanie włączone
    //         {
    //             if (floorLeft.read() > LEFT_FLOOR_THRESHOLD || floorRight.read() > RIGHT_FLOOR_THRESHOLD)
    //             {
    //                 calkaBot.backward();
    //                 _delay_ms(LINE_DETCTION_BACKWARD_LENGHT);
    //                 calkaBot.rightTurn();
    //                 _delay_ms(LINE_DETCTION_TURN_LENGHT);
    //             }else{
    //                 calkaBot.forward();
    //             }                
    //         }
    //     }
        
    // }

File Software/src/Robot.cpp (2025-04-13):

#include "../include/Robot.h"
#include "FrontMotor.h"
#include <Arduino.h>
#include "../lib/SoftPWM.h"
#include "../include/config.h"
#include "../include/Sensor.h"


Robot::Robot(volatile uint8_t* ddr, volatile uint8_t* port, 
             uint8_t pinForwardL, uint8_t pinForwardR, uint8_t pinBackwardL, uint8_t pinBackwardR) 
    : ddr(ddr), port(port), pinForwardL(pinForwardL), pinForwardR(pinForwardR), 
      pinBackwardL(pinBackwardL), pinBackwardR(pinBackwardR){

       

        *ddr |= (1 << pinForwardL) | (1 << pinForwardR)
          | (1 << pinBackwardL) | (1 << pinBackwardR);

        *port &= ~((1 << pinForwardL) | (1 << pinForwardR) 
            | (1 << pinBackwardL) | (1 << pinBackwardR));
      }

void Robot::setSpeed(uint8_t speedLeft, uint8_t speedRight) {
    
//   Palatis::SoftPWM.set(0, 255); // Kanał 0 (pin 13): wartość 100
//   Palatis::SoftPWM.set(1, 255); // Kanał 1 (pin 12): wartość 100
    
}

void Robot::forward() {
    *port |= (1 << pinForwardL) | (1 << pinForwardR);
    *port &= ~((1 << pinBackwardL) | (1 << pinBackwardR));
}

void Robot::backward() {
    *port |= (1 << pinBackwardL) | (1 << pinBackwardR);
    *port &= ~((1 << pinForwardL) | (1 << pinForwardR));
}

void Robot::rightTurn() {
    *port |= (1 << pinForwardL) | (1 << pinBackwardR);
    *port &= ~((1 << pinBackwardL) | (1 << pinForwardR));
}

void Robot::leftTurn() {
    *port |= (1 << pinForwardR) | (1 << pinBackwardL);
    *port &= ~((1 << pinForwardL) | (1 << pinBackwardR));
}

void Robot::stop() {
    *port &= ~((1 << pinForwardL) | (1 << pinForwardR) 
             | (1 << pinBackwardL) | (1 << pinBackwardR));
}

void Robot::leftCurve() {
    // Lewe  do przodu, prawe zatrzymane
    

    *port |= (1 << pinForwardR); 
    *port &= ~((1 << pinBackwardR) | (1 << pinForwardL) | (1 << pinBackwardL)); 
}

void Robot::rightCurve() {
    // Prawe do przodu, lewe zatrzymane
    
    *port |= (1 << pinForwardL); 
    *port &= ~((1 << pinBackwardL) | (1 << pinForwardR) | (1 << pinBackwardR)); 
}

void Robot::position(Sensor* left, Sensor* front, Sensor* right, int time, bool direction){
    
    int timeInMs;
    if (direction)
    {
        rightTurn();
        switch (time)
        {
            case 1:
                timeInMs =POSITIONING_RIGHT_TURN_1;
            break;
            case 2:
                timeInMs =POSITIONING_RIGHT_TURN_2;
            break;
            default:
                timeInMs =POSITIONING_RIGHT_TURN_3;
            break;
        }
    }else{
        leftTurn();
        switch (time)
        {
            case 1:
                 timeInMs =POSITIONING_LEFT_TURN_1;
            break;
            case 2:
                timeInMs =POSITIONING_LEFT_TURN_2;
            break;
            default:
                timeInMs =POSITIONING_LEFT_TURN_3;
            break;
        }
    }
    int i = 0;
    while ( i < timeInMs ){
        delay(10);
        i+=10;
        // if(right->read() > FRONT_RIGHT_THRESHOLD || front->read()>FRONT_THRESHOLD || left->read() > FRONT_LEFT_THRESHOLD) //jak coś widzisz to przestań
        //     break;
    }
    
    stop();
}

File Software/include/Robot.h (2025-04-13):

#ifndef ROBOT_H
#define ROBOT_H

#include <avr/io.h>
#include "FrontMotor.h"
#include "../include/Sensor.h"

#define ROBOT_RIGHT_DDR DDRB
#define ROBOT_RIGHT_PORT PORTB
#define ROBOT_RIGHT_PIN PORTB5  

#define ROBOT_LEFT_DDR DDRB
#define ROBOT_LEFT_PORT PORTB
#define ROBOT_LEFT_PIN PORTB4   //Definicje w preprocesorze potrzebne dla poprawnego działania biblioteki SoftPWM

class Robot {
private:
    volatile uint8_t* ddr;    // Wskaźnik na DDR
    volatile uint8_t* port;   // Wskaźnik na PORT
    uint8_t pinForwardL;      // Pin dla lewego przodu
    uint8_t pinForwardR;      // Pin dla prawego przodu
    uint8_t pinBackwardL;     // Pin dla lewego tyłu
    uint8_t pinBackwardR;     // Pin dla prawego tyłu

public:
    Robot(volatile uint8_t* ddr, volatile uint8_t* port, 
          uint8_t pinForwardL, uint8_t pinForwardR, uint8_t pinBackwardL, uint8_t pinBackwardR);

    void setSpeed(uint8_t speed1, uint8_t speed2);

    void forward();
    void backward();
    void leftTurn();
    void rightTurn();
    void leftCurve();
    void rightCurve();
    void stop();

    void position(Sensor* left, Sensor* front, Sensor* right,  int time, bool direction); // 0 - left, 1 - right
};

#endif

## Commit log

2024-04-02 obudowa silnika done
    [Obudowa_Reki.prt, Obudowa_Reki_Tyl.prt, Podstawa.prt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]
2024-04-03 Trzymajka na sharpa
    [Obudowa_Reki.prt, Obudowa_Reki_Tyl.prt, Zlozenie.prt]
2024-04-05 ręka usprawniona, spychacz rozppoczęty
    [CNY-70.prt, GP2Y0A21YK0F.prt, Obudowa_Reki.prt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]
2024-04-15 front sharp connected, setting angle
    [Kepala Servo_SG90.prt, Obudowa_Reki_Tyl.prt, Podstawa.prt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]
2024-04-29 bateria i dupa
    [Akumulator.prt, ArduinoNano.prt, CNY-70.prt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]
2024-05-06 zostaly śrubki chyba
    [Zderzak.prt, Zlozenie_v2.prt, obudowa_tyl.prt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]
2024-05-07 zostaly srubki i klapka z tylu?
    [Obudowa_Reki.prt, Zderzak.prt, Zlozenie_v2.prt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]
2024-05-20 z starego pc
    [Akumulator.prt, Obudowa_Reki.prt, Obudowa_Reki_Tyl.prt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]
2024-05-22 updated NX, almost finished, created KiCAD project
    [CalkaBot_PCB.kicad_pcb, CalkaBot_PCB.kicad_sch, M3_Nakretka.prt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]
2024-05-23 finishing NX with screws
    [M2_Nakretka.prt, M2_Sruba.prt, Obudowa_Reki.prt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]
2024-06-01 working on screws and holes on pcb
    [CalkaBot_PCB.kicad_pcb, CalkaBot_PCB.kicad_sch, CalkaBot_PCB.prt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]
2024-06-03 working on PCB + changes within NX for project review
    [CalkaBot_PCB.kicad_pcb, CalkaBot_PCB.kicad_sch, CalkaBot_PCB.prt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]
2024-08-11 w trakcie ukladania elementow
    [CalkaBot_PCB.kicad_pcb, CalkaBot_PCB.kicad_sch]
2024-09-30 PCB finished ready to send
    [CalkaBot_PCB.kicad_pcb, CalkaBot_PCB.kicad_sch]
2024-10-19 płytka leci a rece sa gotowe do druku
    [CP_Elec_8x10.5.prt, CP_Elec_8x105.prt, C_0805_2012Metric.prt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]
2024-10-19 dobra teraz git xd
    [Reka_Zlozenie.prt, Zlozenie_v2.prt, reka_kolo.prt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]
2024-10-24 working on soft and 2nd version of board
    [CalkaBot_PCB.kicad_sch]
2024-10-25 continue testing board and making program'
2024-11-01 wyslano druga plytke pisze sie praca i program
    [CalkaBot_PCB-B_Cu.gbr, CalkaBot_PCB-B_Mask.gbr, CalkaBot_PCB-B_Paste.gbr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]
2024-11-10 fixed pwm and diodes, continue working on program an soldering
    [CalkaBot_PCB-B_Cu.gbr, CalkaBot_PCB-B_Mask.gbr, CalkaBot_PCB-B_Paste.gbr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]
2024-11-16 tested, robot is driving
    [CalkaBot_PCB.step, Reka_Zlozenie.prt, Zlozenie_v2.prt]
2024-11-18 migrated to platformIO waiting for print, everything works
2024-11-20 kodzik na czas drukowania
    [Zlozenie_v2.prt, reka_kolo_tyl.prt]
2025-02-16 Druga płytka działa i jeździ
    [CalkaBot_PCB.kicad_sch, Zlozenie_v2.prt]
2025-04-02 Updated Pinout with NEW MOTOR after incidento mucho klojegwinto xd
